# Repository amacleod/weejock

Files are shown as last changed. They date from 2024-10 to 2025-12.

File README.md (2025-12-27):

weejock
=======

Wee Jock is a 4x5 wireless keypad with smaller than normal key
spacing.  The name "Wee Jock" is a reference to Terry Pratchett's
[The Wee Free Men][weefreemen], and is meant to convey that this
keypad is more closely spaced than normal MX spacing.

The current design places the switches in a 17mm square grid, meaning
that only small square keycaps will work. ChosFox's [ChocFox][chocfox]
line of keycaps are approximately 16.5mm square, so they ought to work
fine. MBK keycaps are rectangular and will likely interfere with each
other horizontally.

wee jock schematic Wee Jock Schematic

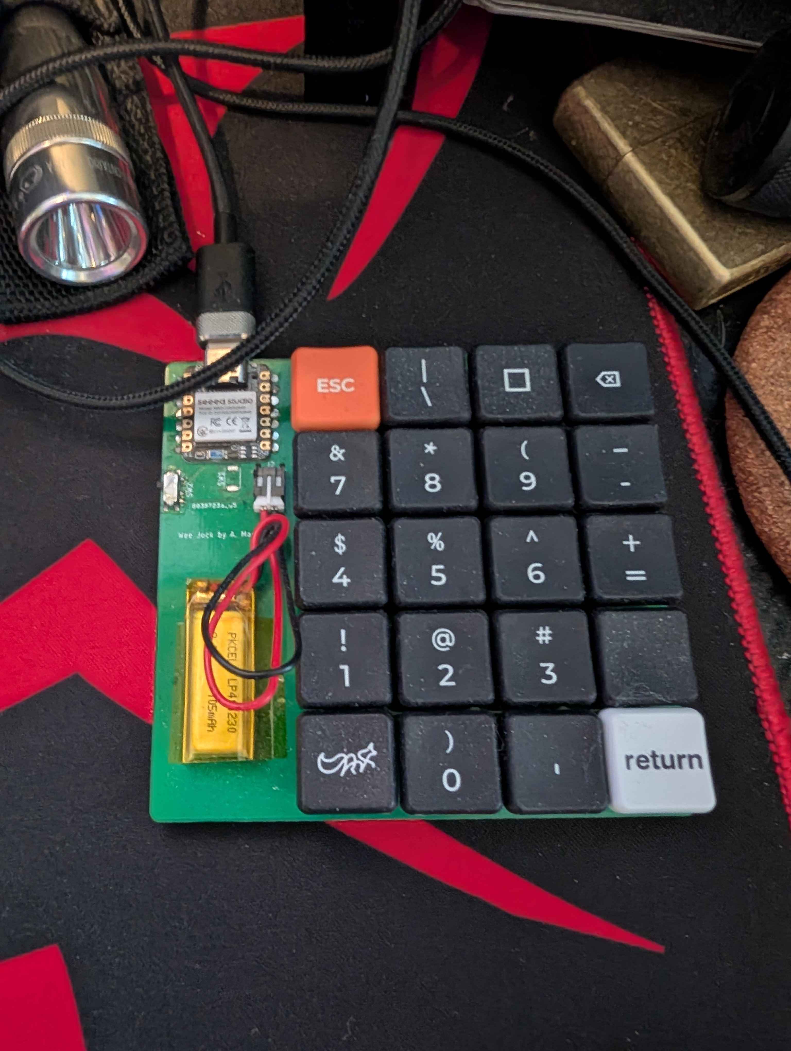
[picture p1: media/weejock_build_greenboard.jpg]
wee jock build photo Wee Jock Build


Bill of Materials
-----------------

In addition to the Gerber file in [WeeJock-0-0-3-GERBER.zip](gerber/WeeJock-0-0-3-GERBER.zip), you will need:
 - 1 Seeed Studio XIAO BLE - [XIAO BLE nRF52840][xiaoble]
   - headers -OR- sockets and pins -OR- solder paste (see below)
 - 1 power switch - [PCM12][pcm12], [CUS-12TB][cus12tb], or equivalent
 - 1 reset button - [B3U-1000P][b3u1000p] or equivalent
 - 1 through-hole, right angle JST-PH-2 jack - [S2B-PH-K-S][s2bphks]
 - 1 3.7V LiPoly battery with a JST connector
 - 20 Kailh Choc v1 key switches (PG1350)
 - 20 diodes with a SOD123 footprint - [1N4148W][diode1n4148w] or equivalent
 - 20 keycaps no larger than 16.5mm by 16.5mm (for example, ChocFox CFX)

In principle, the power switch and JST connector are optional, but
highly recommended for battery operation. If you intend to always use
the keypad connected by USB, you could omit the battery entirely.

> [!WARNING]
> **Polarity Check**: Wee Jock revisions 1, 2, and 3 have the JST-PH
> jack connected to match "Adafruit-style" battery connectors: the
> positive (red) wire should be on the left when viewed from above.
>
> Not all batteries' connectors have the same polarity, so check
> carefully before plugging one in!

If you are hand-soldering, you will need headers for the controller,
as well as pogo pins for the RST and BAT+ pins.
 - 2 seven-pin headers - [PH1-07-UA][ph107ua] (or you can cut longer headers down to size)
   - alternatively you can use sockets such as the [Preci-Dip 310][sockets] series
   - and straight pins such as [Mill-Max 3320][straightpins]
 - 2 spring pins of a height to match the headers - [Mill-Max 0906][pogo0906]

If you intend to surface mount the controller, you will need a way to
handle the RST and BAT+ pads on the back, such as solder paste and a
rework station (or at least a hotplate).

TODO:
 - find a nice way to print a 2D color render of the PCB for inclusion in this README

[weefreemen]: https://en.wikipedia.org/wiki/The_Wee_Free_Men "The Wee Free Men"
[chocfox]: https://chosfox.com/collections/low-profile-keycaps/products/chocfox-bow?variant=43632218767554
[xiaoble]: https://www.seeedstudio.com/Seeed-XIAO-BLE-nRF52840-p-5201.html
[pcm12]: https://www.digikey.com/en/products/detail/c-k/PCM12SMTR/1640112
[cus12tb]: https://www.digikey.com/en/products/detail/nidec-components-corporation/CUS-12TB/1124222
[b3u1000p]: https://www.digikey.com/en/products/detail/omron-electronics-inc-emc-div/B3U-1000P/1534338
[s2bphks]: https://www.digikey.com/en/products/detail/jst-sales-america-inc./S2B-PH-K-S/926626
[diode1n4148w]: https://www.digikey.com/en/products/detail/smc-diode-solutions/1N4148W/6022450
[ph107ua]: https://www.digikey.com/en/products/detail/adam-tech/PH1-07-UA/9830505
[sockets]: https://www.digikey.com/en/products/detail/preci-dip/310-87-115-41-001101/3757353
[straightpins]: https://www.digikey.com/en/products/detail/mill-max-manufacturing-corp/3320-0-00-15-00-00-03-0/4147392
[pogo0906]: https://www.digikey.com/en/products/detail/mill-max-manufacturing-corp/0906-2-15-20-75-14-11-0/1147050

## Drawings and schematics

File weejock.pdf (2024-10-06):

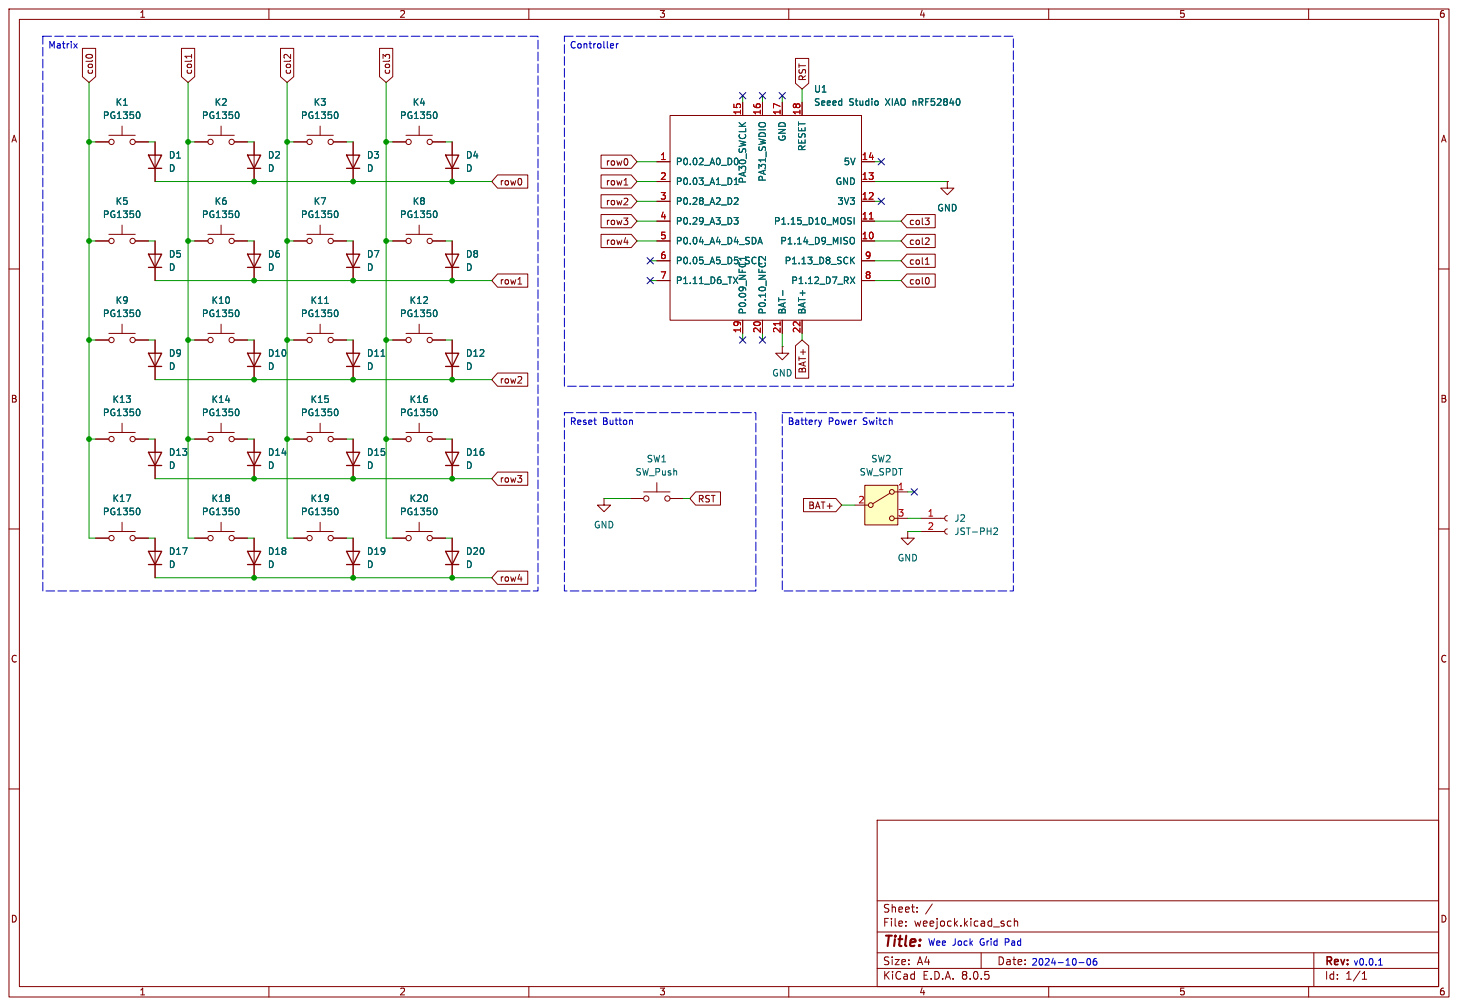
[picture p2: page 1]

Id: 1/1 Title: File: weejock.kicad_sch Sheet: /

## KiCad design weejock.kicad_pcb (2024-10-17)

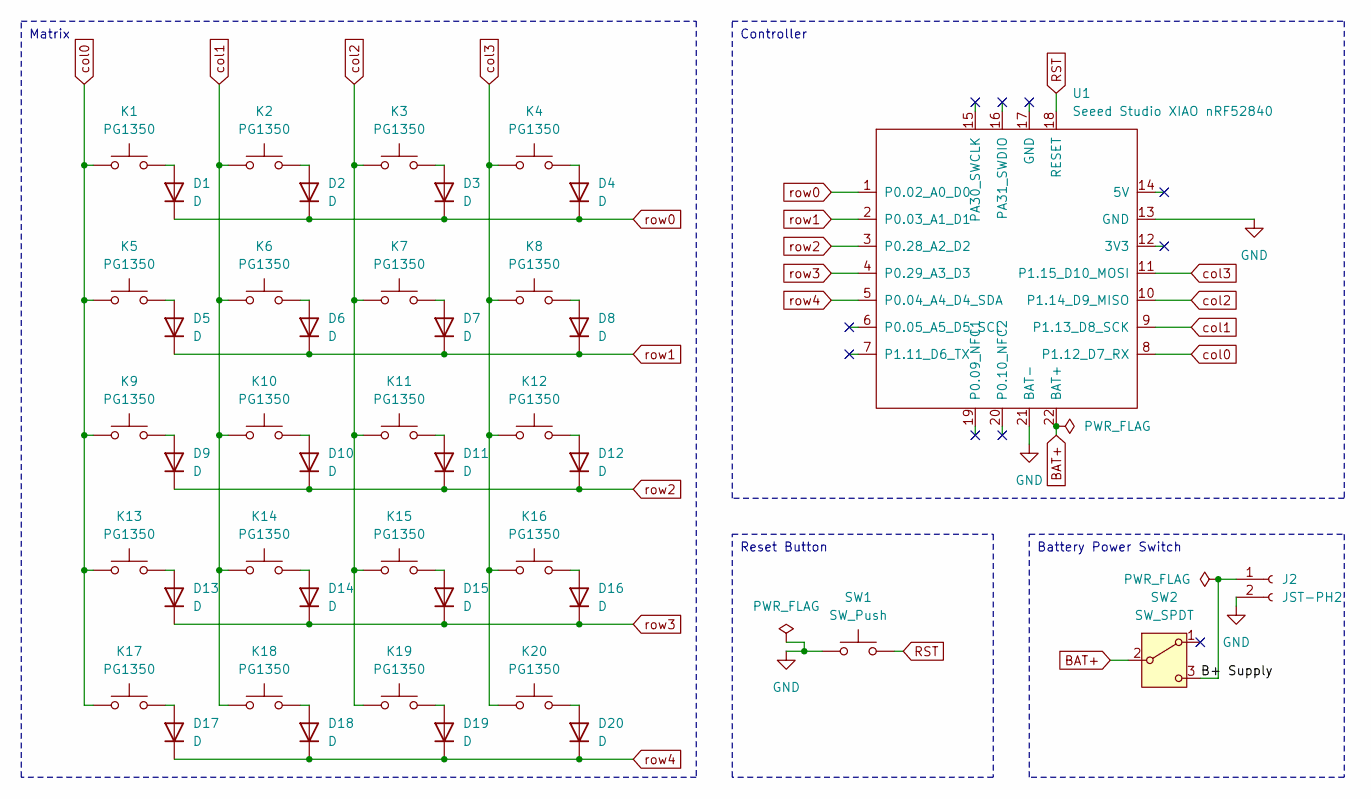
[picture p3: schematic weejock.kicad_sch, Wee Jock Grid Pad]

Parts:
D1, D2, D3, D4, D5, D6, D7, D8, D9, D10, D11, D12, D13, D14, D15, D16, D17, D18, D19, D20: D; D_SOD-123
J2: JST-PH2; JST_PH_S2B-PH-K_1x02_P2.00mm_Horizontal
K1, K2, K3, K4, K5, K6, K7, K8, K9, K10, K11, K12, K13, K14, K15, K16, K17, K18, K19, K20: PG1350; SW_Kailh_Choc_V1
SW1: SW_Push; SW_SPST_B3U-1000P
SW2: SW_SPDT; SW_SPDT_PCM12
U1: Seeed Studio XIAO nRF52840; Castellated XIAO with BAT+ and RST

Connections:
/B+ Supply: J2.1, SW2.3 (C)
BAT+: SW2.2 (B), U1.22 (BAT+)
GND: J2.2, SW1.1, U1.13 (GND), U1.21 (BAT-)
unnamed: D1.2 (A), K1.2
unnamed: D2.2 (A), K2.2
unnamed: D3.2 (A), K3.2
unnamed: D4.2 (A), K4.2
unnamed: D5.2 (A), K5.2
unnamed: D6.2 (A), K6.2
unnamed: D7.2 (A), K7.2
unnamed: D8.2 (A), K8.2
unnamed: D9.2 (A), K9.2
unnamed: D10.2 (A), K10.2
unnamed: D11.2 (A), K11.2
unnamed: D12.2 (A), K12.2
unnamed: D13.2 (A), K13.2
unnamed: D14.2 (A), K14.2
unnamed: D15.2 (A), K15.2
unnamed: D16.2 (A), K16.2
unnamed: D17.2 (A), K17.2
unnamed: D18.2 (A), K18.2
unnamed: D19.2 (A), K19.2
unnamed: D20.2 (A), K20.2
RST: SW1.2, U1.18 (RESET)
col0: K1.1, K5.1, K9.1, K13.1, K17.1, U1.8 (P1.12_D7_RX)
col1: K2.1, K6.1, K10.1, K14.1, K18.1, U1.9 (P1.13_D8_SCK)
col2: K3.1, K7.1, K11.1, K15.1, K19.1, U1.10 (P1.14_D9_MISO)
col3: K4.1, K8.1, K12.1, K16.1, K20.1, U1.11 (P1.15_D10_MOSI)
row0: D1.1 (K), D2.1 (K), D3.1 (K), D4.1 (K), U1.1 (P0.02_A0_D0)
row1: D5.1 (K), D6.1 (K), D7.1 (K), D8.1 (K), U1.2 (P0.03_A1_D1)
row2: D9.1 (K), D10.1 (K), D11.1 (K), D12.1 (K), U1.3 (P0.28_A2_D2)
row3: D13.1 (K), D14.1 (K), D15.1 (K), D16.1 (K), U1.4 (P0.29_A3_D3)
row4: D17.1 (K), D18.1 (K), D19.1 (K), D20.1 (K), U1.5 (P0.04_A4_D4_SDA)

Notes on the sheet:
Reset Button
Matrix
Controller
Battery Power Switch

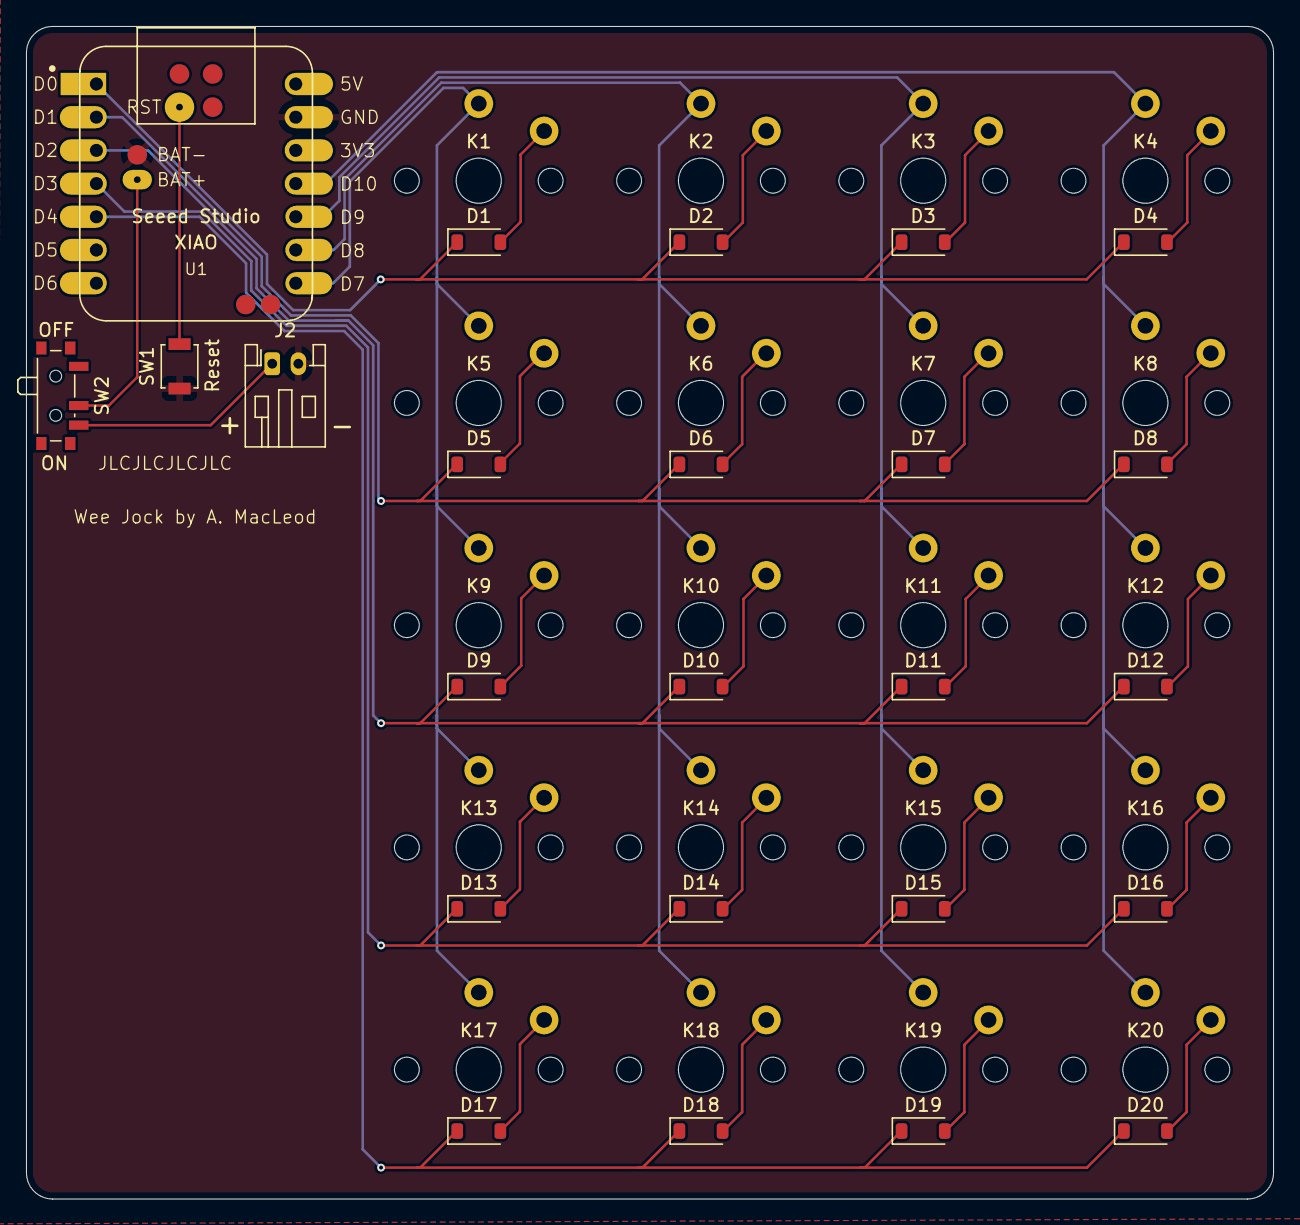
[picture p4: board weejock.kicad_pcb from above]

Board: 2 copper layers, 95.4 x 89.7 mm, 44 parts (0 on the bottom side), 33 nets.

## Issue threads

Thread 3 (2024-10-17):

Label SW1 as Reset

amacleod, 2024-10-17:
And maybe move its footprint left a little.

Closed 2024-10-17.

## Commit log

2024-10-06 Initial commit for Wee Jock grid pad
    [weejock.kicad_pcb, weejock.kicad_sch]
2024-10-06 Plot of schematic v0.0.1
2024-10-06 Attempting to include schematic in README
2024-10-06 Let us try the schematic with SVG instead of PNG.
2024-10-06 Beginning to assign footprints.
    [weejock.kicad_pcb, weejock.kicad_sch]
2024-10-06 Moving footprints around on the PCB layout.
    [weejock.kicad_pcb]
2024-10-07 Routing traces.
    [weejock.kicad_pcb]
2024-10-07 Rerouting stuff to not be too near the edge of the board.
    [weejock.kicad_pcb]
2024-10-07 Perhaps misguided attempt to make hand-soldering holes for surface mount back pads.
    [weejock.kicad_pcb]
2024-10-07 Fixing up footprints for better routing and access around XIAO.
    [weejock.kicad_pcb, weejock.kicad_sch]
2024-10-07 Forgot to check in new footprint for Seeed XIAO.
2024-10-07 After-effects of a Gerber plot.
    [weejock.kicad_pcb]
2024-10-11 Version 0.0.2 - use footprint that is both SMT and through hole friendly, and fix JST footprint.
    [weejock.kicad_pcb, weejock.kicad_sch]
2024-10-11 Gerber ZIP for Wee Jock v0.0.2
2024-10-11 Adding BOM to README
2024-10-11 Minor changes, I think due to moving some text.
    [weejock.kicad_pcb, weejock.kicad_sch]
2024-10-17 Rev 3: Fix up pad placement and silkscreen labels, as well as repositioning components a little. (#5)
    * Correcting XIAO BLE footprint to reverse accidental mirroring of pads.
    * Neatening power switch and adding ON/OFF labels.
    * Labeling reset button.
    * Moving JST jack for better keycap clearance, and adding +/- labels.
    * Messing with labels.
    * Update sheet metadata to reflect version number 0.0.3
    [weejock.kicad_pcb, weejock.kicad_sch]
2024-10-17 Gerber ZIP for Wee Jock v0.0.3
2024-10-17 Update Gerber link to v0.0.3
2024-10-17 Pin labels for XIAO
    [weejock.kicad_pcb]
2024-10-17 Update 0-0-3 Gerbers in place to include controller pin labels.
2024-10-17 More XIAO labels.
    [weejock.kicad_pcb]
2024-10-17 Yet another in-place Gerber replacement for labels.
